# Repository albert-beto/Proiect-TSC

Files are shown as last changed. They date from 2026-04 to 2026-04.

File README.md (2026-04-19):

# InkTime v6

InkTime v6 este o platformă wearable construită pentru autonomie mare și interacțiune discretă. Dispozitivul folosește un display e-paper, conectivitate Bluetooth Low Energy, senzori de mișcare, feedback haptic și alimentare dintr-un acumulator LiPo încărcat prin USB-C.

La nivel de arhitectură, tot sistemul este orchestrat de un **Nordic nRF52840**, care gestionează radio-ul, magistralele digitale și logica de power management.

---

## Ce face dispozitivul

InkTime v6 este gândit ca un smartwatch sau dispozitiv portabil cu consum redus, capabil să rămână activ perioade lungi de timp între încărcări.

Funcțiile principale sunt:

- afișare pe e-paper, cu consum aproape nul în stare statică;
- comunicație BLE;
- detecție de mișcare și numărare pași;
- feedback haptic;
- încărcare prin USB-C;
- monitorizare a stării bateriei.

---

## Diagramă bloc

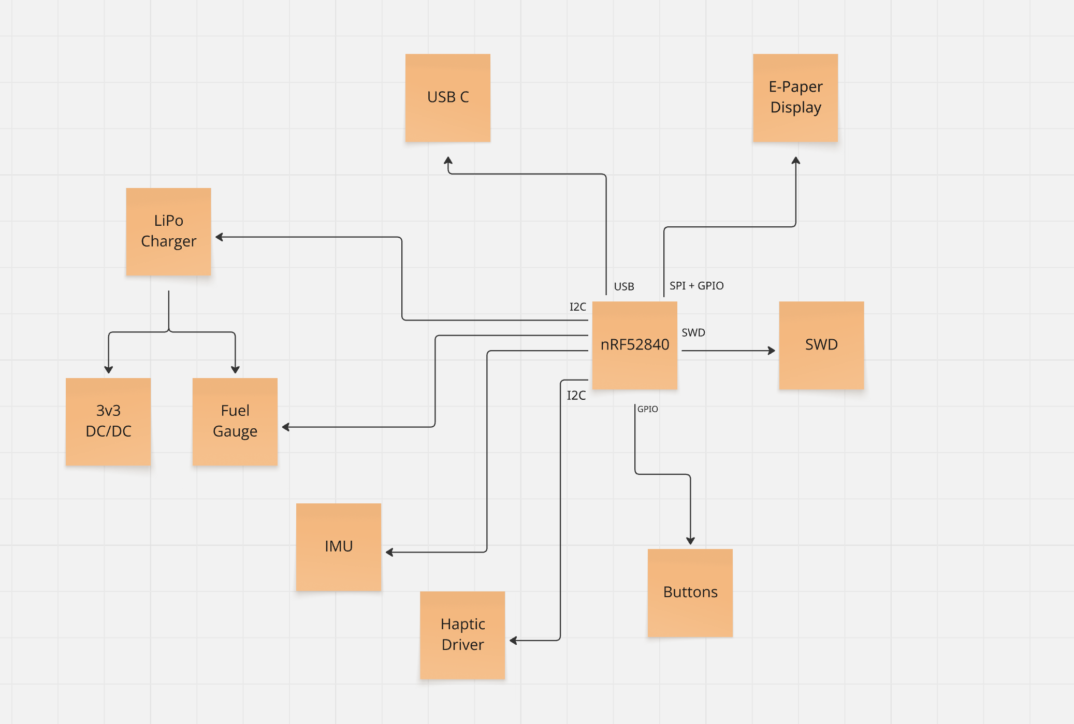
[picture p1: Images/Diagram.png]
Diagrama bloc InkTime


---

## Nucleul sistemului

### nRF52840

Controlerul principal este **nRF52840**, un SoC cu ARM Cortex-M4F, memorie Flash de 1 MB, 256 KB RAM, radio 2.4 GHz multiprotocol și interfață USB 2.0 Full-Speed integrată.

Acesta a fost ales pentru că permite integrarea într-un singur cip a mai multor funcții importante:

- comunicație BLE 5.0;
- control al perifericelor pe I2C și SPI;
- suport USB nativ;
- moduri eficiente de consum redus.

Pentru tactare sunt folosite două cristale externe:

- `X1` — 32 MHz, pentru **HFCLK**;
- `X2` — 32.768 kHz, pentru **LFCLK**.

---

## Interfețe și periferice

### Display e-paper

Interfața principală a utilizatorului este un display e-paper conectat printr-un FPC cu 24 de pini (`J3`). Pentru că afișajul este bistabil, energia este consumată în principal în timpul actualizării, nu în perioada în care imaginea rămâne neschimbată.

Controlul acestui bloc este împărțit în trei părți.

#### 1. Semnale digitale

Comunicarea cu displayul se face printr-o interfață SPI și linii auxiliare:

- `MOSI`
- `SCK`
- `EPD_CS`
- `EPD_DC`
- `EPD_RST`
- `EPD_BUSY`

#### 2. Tensiuni bias pentru panou

Driverul displayului are nevoie de mai multe tensiuni specifice pentru matricea TFT. Acestea sunt obținute cu ajutorul unui mic boost converter și al unei rețele de diode Schottky și condensatoare.

Tensiunile generate sunt:

- `VGH`
- `VGL`
- `VSH`
- `VSL`

#### 3. Oprirea completă a alimentării displayului

Alimentarea de 3.3 V a ansamblului EPD poate fi întreruptă complet printr-un load switch realizat cu MOSFET-ul P-channel **DMG2305UX** (`Q1`). Acesta este comandat de semnalul `EPD_PWR`.

### Accelerometru

Pentru detectarea activității este folosit **BMA423** (`IC2`), un accelerometru digital pe 3 axe.

Rolurile sale în proiect sunt:

- detecția de mișcare;
- step counting;
- generarea de evenimente prin întreruperi.

Componenta este utilizată în **mod I2C**, iar pinul `CSB` este conectat la `VDDIO` pentru a forța această configurație. Cele două ieșiri de întrerupere, `INT1` și `INT2`, sunt rutate separat spre microcontroller.

### Haptic

Blocul de feedback haptic se bazează pe **DRV2605** (`IC1`), controlat pe I2C. Activarea sau dezactivarea lui se face din semnalul `HAPTIC_EN`, conectat la un GPIO al MCU-ului.

Ieșirile `OUT+` și `OUT−` merg direct spre actuatorul haptic.

### Butoane

Sunt implementate trei butoane fizice:

- `SW_UP`
- `SW_DN`
- `SW_ENT`

Fiecare este conectat la câte un GPIO și are:

- pull-up extern de 10 kΩ;
- circuit RC de debounce cu 1 µF la GND.

---

## Alimentare

### USB-C

Conectorul `J1` este un **USB Type-C** (`KH-TYPE-C-16P`) folosit pentru alimentare și pentru conexiunea USB 2.0. În layout sunt rutate doar liniile necesare proiectului.

### Protecție ESD

Pentru protejarea liniilor USB și CC este folosit **USBLC6-2SC6Y**, plasat aproape de conector.

### Încărcător Li-Po

Gestionarea încărcării acumulatorului este făcută de **BQ25180** (`IC4`).

Acest circuit oferă:

- configurare prin I2C;
- curent de încărcare programabil;
- semnalizare de evenimente prin pinul `PMIC_INT`;
- protecție termică.

### Fuel gauge

Monitorizarea bateriei este realizată de **MAX17048** (`U1`), care măsoară tensiunea celulei și estimează nivelul de încărcare.

În design:

- comunică pe magistrala I2C comună;
- folosește semnalul `ALERT` pentru notificări către MCU.

### Convertor DC/DC

Subsistemul de putere include și **RT6160AWSC** (`IC3`), folosit ca convertor DC/DC.

---

## Programare și debug

Pentru flash și depanare este prevăzut un conector **Tag-Connect TC2030-IDC** (`J2`), cu 6 pini, fără header montat permanent pe PCB.

Liniile expuse sunt:

- `VTREF (3.3V)`
- `SWDIO`
- `SWDCLK`
- `SWO`
- `nRESET`
- `GND`

Pe placă există și test pads dedicate:

- `TP_SWDIO`
- `TP_SWDCLK`
- `TP_SWO`
- `TP_RESET`
- `TP_3.3V`
- `TP_GND`

---

## Alocarea pinilor MCU

Mai jos este rezumat mapping-ul relevant pentru nRF52840.

| Pin nRF52840 | Rol | Tip | Observație |
|---|---|---|---|
| **P0.00** | Cristal 32.768 kHz | OSC | Pin dedicat LFXO |
| **P0.01** | Cristal 32.768 kHz | OSC | Pin dedicat LFXO |
| **P0.09** | neconectat | GPIO | rezervat |
| **P0.10** | neconectat | GPIO | rezervat |
| **P0.13** | `MOSI` spre EPD | SPIM | rutare scurtă spre zona displayului |
| **P0.14** | `SCK` spre EPD | SPIM | grupat cu `MOSI` |
| **P0.18** | reset extern | nRESET | pin dedicat |
| **P0.19** | `EPD_CS` | SPIM | asociat interfeței EPD |
| **P0.20** | `EPD_DC` | GPIO | control display |
| **P0.21** | `EPD_RST` | GPIO | reset display |
| **P0.22** | `SWO` | SWO | debug |
| **P0.23** | `EPD_BUSY` | GPIO input + INT | semnal status display |
| **P0.24** | `EPD_PWR` | GPIO | comandă load switch |
| **P0.25** | `HAPTIC_EN` | GPIO | enable pentru DRV2605 |
| **P0.26** | `SDA` | TWIM | magistrală I2C |
| **P0.27** | `SCL` | TWIM | magistrală I2C |
| **P0.28** | neconectat | analog | rezervat |
| **P0.29** | neconectat | GPIO | rezervat |
| **P0.30** | neconectat | GPIO | rezervat |
| **P0.31** | neconectat | GPIO | rezervat |
| **P1.00** | `PMIC_INT` | GPIO input + INT | evenimente de charging |
| **P1.01** | `SW_UP` | GPIO input | buton |
| **P1.02** | `SW_DN` | GPIO input | buton |
| **P1.03** | `SW_ENT` | GPIO input | buton |
| **P1.04** | `IMU_INT1` | GPIO input + INT | eveniment accelerometru |
| **P1.05** | `IMU_INT2` | GPIO input + INT | eveniment accelerometru |
| **P1.06** | `ALERT` | GPIO input + INT | alertă baterie |
| **P1.07** | EPD spre Q3 | GPIO / PWM | comandă auxiliară |
| **SWDCLK** | programare / debug | dedicat | SWD |
| **SWDIO** | programare / debug | dedicat | SWD |
| **VBUS** | detectare USB | USB PHY | sensing VBUS |
| **D+ / D−** | USB 2.0 FS | USB PHY | interfață USB |

---

## Consum și autonomie

### Curent estimat în standby

| Componentă | Curent tipic | Observații |
|---|---:|---|
| nRF52840 (System ON, RAM retention, RTC, LFXO) | ~1.5 µA | radio inactiv |
| BMA423 (low-power, 25 Hz) | ~4 µA | step detection activ |
| BQ25180 (quiescent, no charge) | ~6 µA | |
| MAX17048 (active measurement) | ~23 µA | hibernate ~3 µA |
| DRV2605 (EN=LOW) | < 1 µA | shutdown |
| RT6160 (PFM, fără sarcină) | ~25 µA | ultra-low-quiescent |
| E-paper | ~0 µA | fără refresh |
| Leakage PCB + diode | ~5 µA | estimat |
| **Total** | **≈ 65 µA** | |

### Autonomie estimată pentru 150 mAh

Presupunând un profil de utilizare tipic:

- 23 h 45 min standby la 65 µA → aproximativ 1.54 mAh/zi;
- refresh-uri de ecran → aproximativ 0.2 mAh/zi;
- evenimente haptice → aproximativ 0.01 mAh/zi.

Consum total zilnic estimat:

**≈ 1.75 mAh/zi**

Autonomie rezultată:

**150 mAh / 1.75 mAh pe zi ≈ 85 zile**

---

## Note de implementare

În faza curentă de proiect au fost acceptate câteva compromisuri și excepții:

- pentru rezistoare și condensatoare mici au fost păstrate modele 3D placeholder;
- au fost aprobate 6 erori legate de modelele 3D ale butoanelor;
- au fost acceptate erori de tip **Overlap** și **Copper clearance** asociate utilizării tehnicii **via-in-pad**.

---

## Concluzie tehnică

InkTime v6 este un sistem compact orientat spre consum redus, în care displayul bistabil, BLE-ul, senzorii și managementul de putere sunt integrate în jurul nRF52840. Arhitectura a fost gândită pentru un dispozitiv portabil capabil să ofere autonomie mare, funcții utile de interacțiune și o interfață modernă cu utilizatorul.

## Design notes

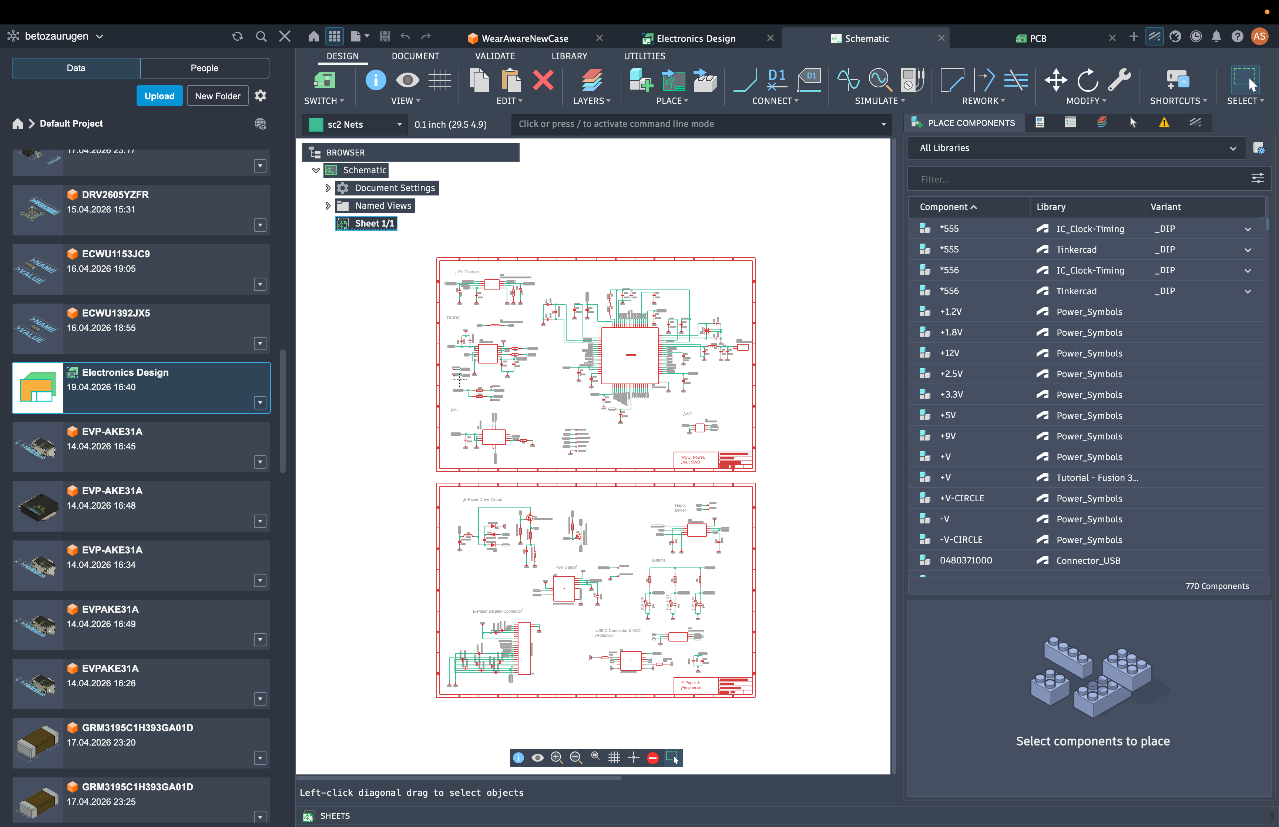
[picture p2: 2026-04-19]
Images/IntTime3.png

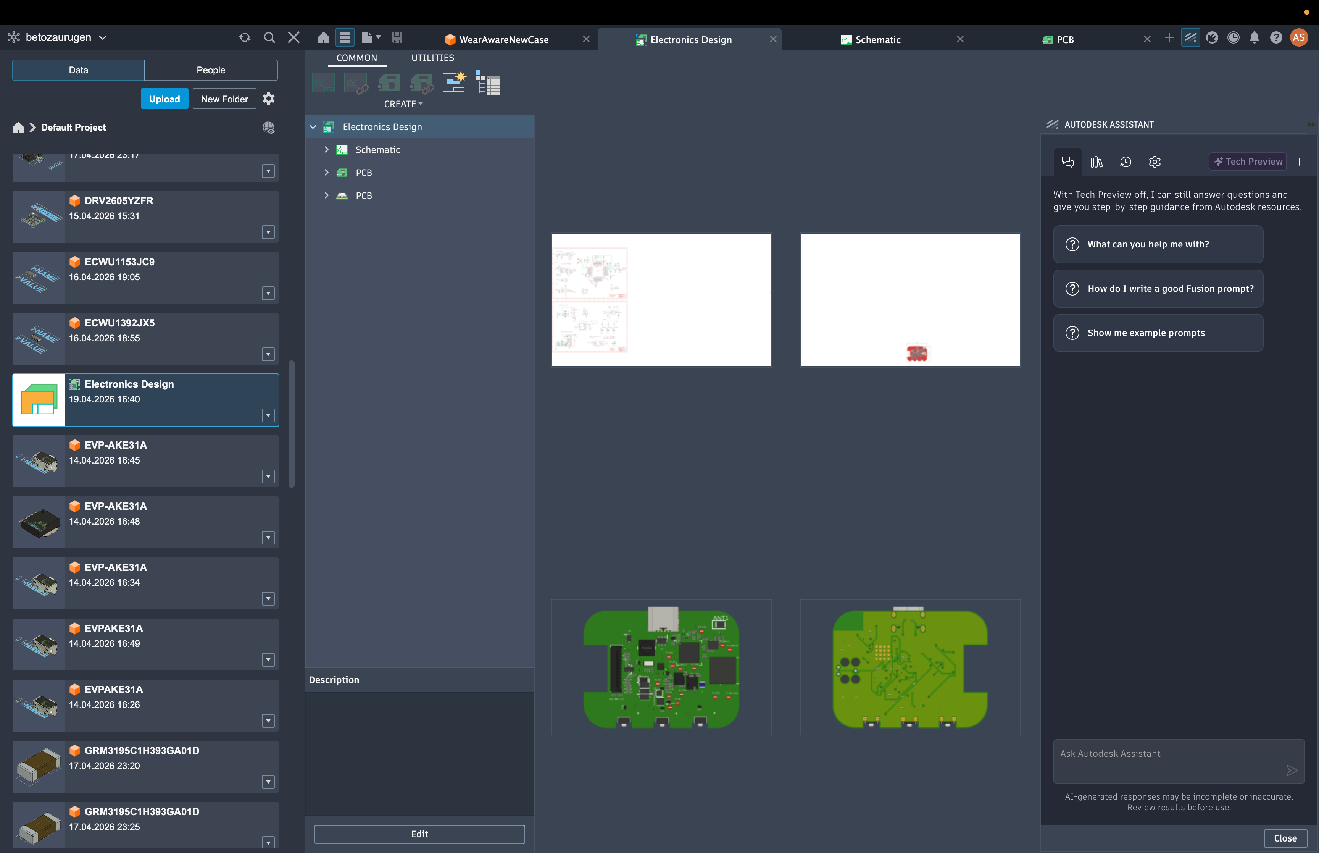
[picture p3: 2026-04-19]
Images/InkTime4.png

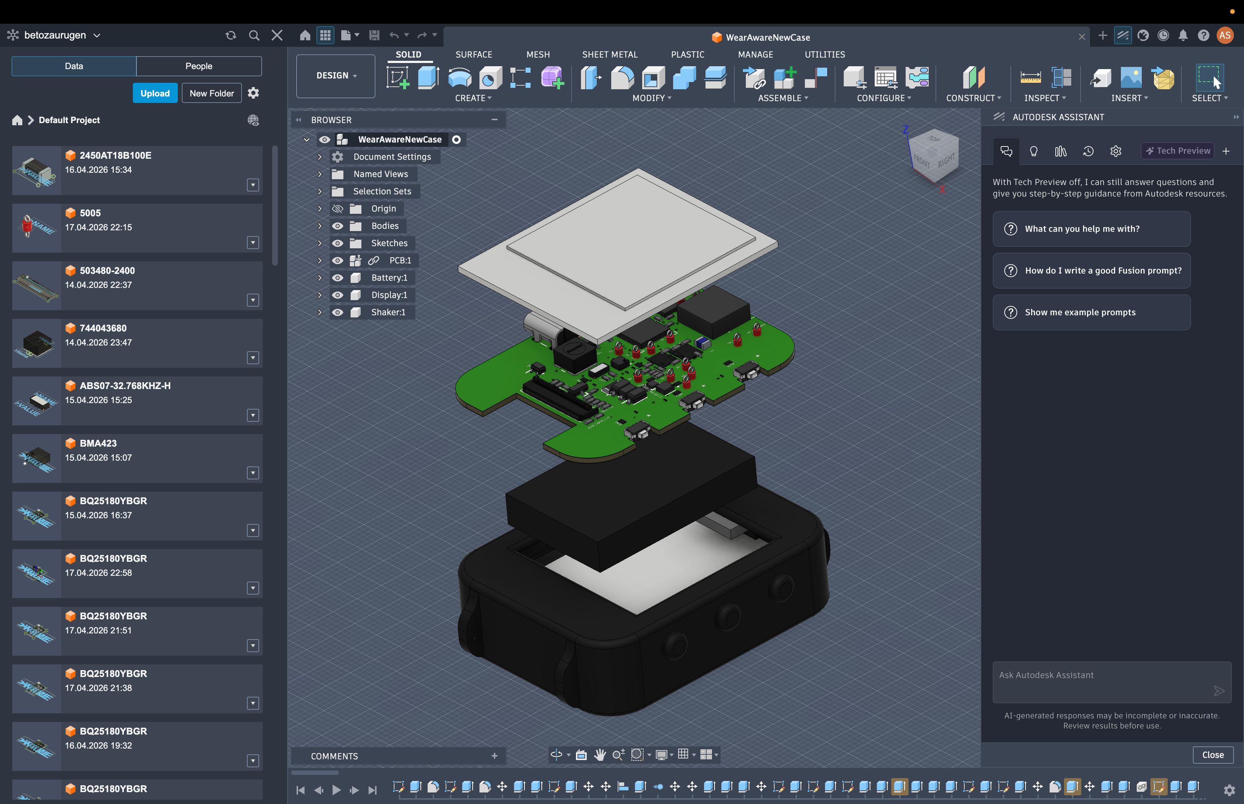
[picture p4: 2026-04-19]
Images/InkTime1.png

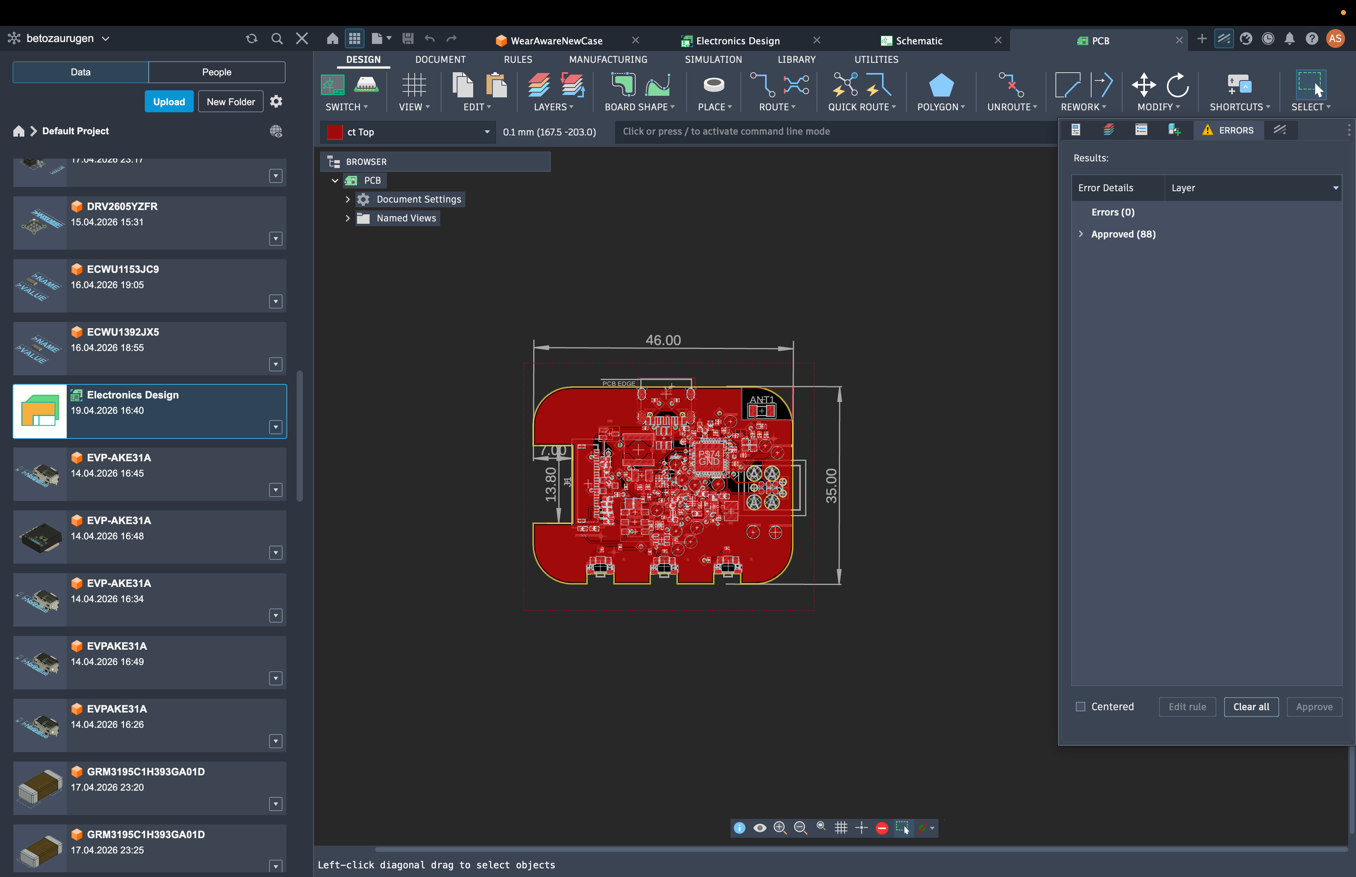
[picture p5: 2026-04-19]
Images/InkTime2.png

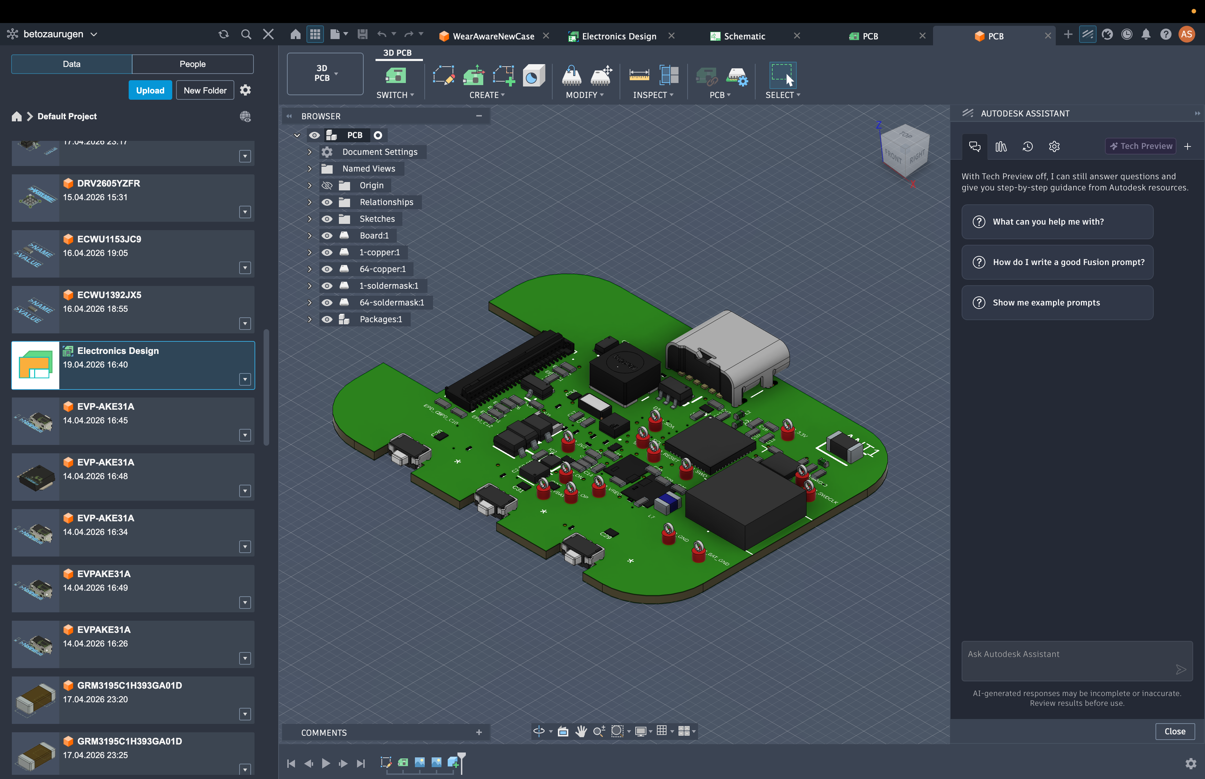
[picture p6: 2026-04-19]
Images/InkTime5.png

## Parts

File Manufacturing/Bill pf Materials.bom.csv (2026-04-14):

Qty | Value | Device | Package | Parts | Description | ARROW_PART_NUMBER | ARROW_PRICE-STOCK | AVAILABILITY | CHECK_PRICES | COPYRIGHT | DESCRIPTION | DIGI-KEY_PART_NUMBER_1 | DIGI-KEY_PART_NUMBER_2 | DIGI-KEY_PART_NUMBER_3 | HEIGHT | JLCPCB | MANUFACTURER_NAME | MANUFACTURER_PART_NUMBER | MF | MFR_NAME | MOUSER_PART_NUMBER | MOUSER_PRICE-STOCK | MP | PACKAGE | POPULARITY | PRICE | PROD_ID | PURCHASE-URL | SNAPEDA_LINK | TP_SIGNAL_NAME | VALUE
3 |  | 2025-10-22_07-23-44_LIBRARY_EVP-AKE31ASW_EVP-AKE31A_PAN | 2025-10-22_07-23-44_LIBRARY_SW_EVP-AKE31A_PAN | SW_DN, SW_ENT, SW_UP |  |  |  |  |  | Copyright (C) 2025 Ultra Librarian. All rights reserved. |  | P123437TR-ND | P123437CT-ND | P123437DKR-ND |  |  | Panasonic | EVP-AKE31A
1 |  | ESP32_C6_LIBRARY_7_JUMPER_SJ | ESP32_C6_LIBRARY_7_JUMPER_SJ | SJ1 | SMD solder JUMPER |  |  |  |  |  |  |  |  |  |  |  |  |  |  |  |  |  |  |  | 3
3 | 0 | CPF0201D7K68C1_CPF0201D7K68C1 | CPF0201D7K68C1_0201 | R2, R3, R4 | 7.68k 0201 Thin Film Surface Mount Fixed Resistor +/-0.5% 0.031W CPF0201D7K68C1
4 | 0.1uF | GRM011R60J152KE01L_2_GRM011R60J152KE01L | GRM011R60J152KE01L_2_CAPC0201X13N | C23, C27, C34, C42 | Check availability |  |  | In Stock | https://www.snapeda.com/parts/GRM011R60J152KE01L/Murata/view-part/?ref=eda |  | SMD Capacitor X5R(EIA) with Capacitance: 1500pF Tol. 10%. Rated Voltage: 6.3Vdc |  |  |  |  |  |  |  | Murata |  |  |  | GRM011R60J152KE01L | 0201 Murata |  | None |  |  | https://www.snapeda.com/parts/GRM011R60J152KE01L/Murata/view-part/?ref=snap
1 | 0.1uF/50V | NORDIC_NRF_3_CAPACITOR_0201_L | NORDIC_NRF_3_RESC0201_L | EPD-C5 | Generic chip capacitor
1 | 0.47 | CPF0201D7K68C1_CPF0201D7K68C1 | CPF0201D7K68C1_0201 | R1_EP_DR | 7.68k 0201 Thin Film Surface Mount Fixed Resistor +/-0.5% 0.031W CPF0201D7K68C1
1 | 1.0uF | NORDIC_NRF_3_CAPACITOR_0402_L | NORDIC_NRF_3_RESC0402_L | C15 | Generic chip capacitor
4 | 100nF | NORDIC_NRF_3_CAPACITOR_0201_L | NORDIC_NRF_3_RESC0201_L | C5, C7, C8, C12 | Generic chip capacitor
1 | 100pF | NORDIC_NRF_3_CAPACITOR_0201_L | NORDIC_NRF_3_RESC0201_L | C11 | Generic chip capacitor
5 | 10K | CPF0201D7K68C1_CPF0201D7K68C1 | CPF0201D7K68C1_0201 | R2_EP_DR, R5, R7, R8, R_POWER_EPD | 7.68k 0201 Thin Film Surface Mount Fixed Resistor +/-0.5% 0.031W CPF0201D7K68C1
1 | 10K | ERA-1AEB3401C_CPF0201D7K68C1 | ERA-1AEB3401C_0201 | R1 | 7.68k 0201 Thin Film Surface Mount Fixed Resistor +/-0.5% 0.031W CPF0201D7K68C1
3 | 10uF | NORDIC_NRF_3_CAPACITOR_0402_L | NORDIC_NRF_3_RESC0402_L | C1-EP-DR, C24, C39 | Generic chip capacitor
1 | 10µH | NORDIC_NRF_2_INDUCTOR_0402_L | NORDIC_NRF_2_RESC0402_L | L2 | Generic chip inductor
4 | 12pF | NORDIC_NRF_3_CAPACITOR_0201_L | NORDIC_NRF_3_RESC0201_L | C1, C2, C17, C18 | Generic chip capacitor
1 | 15nH | NORDIC_NRF_2_INDUCTOR_0402_L | NORDIC_NRF_2_RESC0402_L | L3 | Generic chip inductor
2 | 1pF | NORDIC_NRF_3_CAPACITOR_0201_L | NORDIC_NRF_3_RESC0201_L | C3, C4 | Generic chip capacitor
6 | 1uF | GRM011R60J152KE01L_2_GRM011R60J152KE01L | GRM011R60J152KE01L_2_CAPC0201X13N | C29, C30, C31, C32, C37, C38 | Check availability |  |  | In Stock | https://www.snapeda.com/parts/GRM011R60J152KE01L/Murata/view-part/?ref=eda |  | SMD Capacitor X5R(EIA) with Capacitance: 1500pF Tol. 10%. Rated Voltage: 6.3Vdc |  |  |  |  |  |  |  | Murata |  |  |  | GRM011R60J152KE01L | 0201 Murata |  | None |  |  | https://www.snapeda.com/parts/GRM011R60J152KE01L/Murata/view-part/?ref=snap
9 | 1uF/50V | NORDIC_NRF_3_CAPACITOR_0402_L | NORDIC_NRF_3_RESC0402_L | EPD_C1, EPD_C2, EPD_C6, EPD_C7, EPD_C8, EPD_C9, EPD_C10, EPD_C11, EPD_C12 | Generic chip capacitor
1 | 2.2 | CPF0201D7K68C1_CPF0201D7K68C1 | CPF0201D7K68C1_0201 | R_TYPE_SEL | 7.68k 0201 Thin Film Surface Mount Fixed Resistor +/-0.5% 0.031W CPF0201D7K68C1
1 | 20V/4.2A/52mΩ/1.4W | ESP32_C6_LIBRARY_4_ESP32_WROVER_SPARKFUN-DISCRETESEMI_MOSFET_PCH-DMG2305UX-7 | ESP32_C6_LIBRARY_4_ESP32_C6_LIBRARY_4_ESP32_C6_LIBRARY_4_ESP32_C6_LIBRARY_4_ESP32_WROVER_SPARKFUN-DISCRETESEMI_SOT23-3 | Q1 | P-channel MOSFETs |  |  |  |  |  |  |  |  |  |  |  |  |  |  |  |  |  |  |  |  |  | TRAN-14388 |  |  |  | 20V/4.2A/52mΩ/1.4W
2 | 22uF | NORDIC_NRF_3_CAPACITOR_0201_L | NORDIC_NRF_3_RESC0201_L | C19, C33 | Generic chip capacitor
1 | 22uF | NORDIC_NRF_3_CAPACITOR_0402_L | NORDIC_NRF_3_RESC0402_L | C25 | Generic chip capacitor
1 | 2450AT18B100E | 2450AT18B100E_2450AT18B100E | 2450AT18B100E_ANTC3216X140N | ANT1 | Antennas 2.45GHz ANTENNA | 2450AT18B100E | https://www.arrow.com/en/products/2450at18b100e/johanson-dielectrics?utm_currency=USD&region=nac |  |  |  | Antennas 2.45GHz ANTENNA |  |  |  | 1.4mm |  | JOHANSON TECHNOLOGY | 2450AT18B100E |  |  | 609-2450AT18B100E | https://www.mouser.co.uk/ProductDetail/Johanson-Technology/2450AT18B100E?qs=yCnrNFeXz%252Bh5MFsFIXGZGA%3D%3D
1 | 3.9nH | NORDIC_NRF_2_INDUCTOR_0402_L | NORDIC_NRF_2_RESC0402_L | L1 | Generic chip inductor
1 | 32.768kHz | NORDIC_NRF_1_XTAL_32KHZ | NORDIC_NRF_1_XTAL_3215_N | X2
1 | 32MHz | NORDIC_NRF_XTAL_32MHZ | NORDIC_NRF_BT-XTAL_2016_N | X1
2 | 3K3 | CPF0201D7K68C1_CPF0201D7K68C1 | CPF0201D7K68C1_0201 | R17, R18 | 7.68k 0201 Thin Film Surface Mount Fixed Resistor +/-0.5% 0.031W CPF0201D7K68C1
2 | 4.7uF | NORDIC_NRF_3_CAPACITOR_0402_L | NORDIC_NRF_3_RESC0402_L | C14, C43 | Generic chip capacitor
1 | 4.7uF/25V | NORDIC_NRF_3_CAPACITOR_0402_L | NORDIC_NRF_3_RESC0402_L | C2-EP-DR | Generic chip capacitor
3 | 4.7µF | NORDIC_NRF_3_CAPACITOR_0402_L | NORDIC_NRF_3_RESC0402_L | C6, C20, C21 | Generic chip capacitor
1 | 47nF | NORDIC_NRF_3_CAPACITOR_0201_L | NORDIC_NRF_3_RESC0201_L | C16 | Generic chip capacitor
1 | 503480-2400 | 503480-2400_503480-2400 | 503480-2400_5034802400 | J1 | FFC & FPC Connectors 0.5mm FPC RA SMT Dual Contact 24Ckt |  |  |  |  |  | FFC & FPC Connectors 0.5mm FPC RA SMT Dual Contact 24Ckt |  |  |  | 1.87mm |  | Molex | 503480-2400 |  |  | 538-503480-2400 | https://www.mouser.co.uk/ProductDetail/Molex/503480-2400?qs=OAhjpuo3Vu7efIoxFh9AOw%3D%3D
2 | 5K1 | CPF0201D7K68C1_CPF0201D7K68C1 | CPF0201D7K68C1_0201 | R1_USB, R2_USB | 7.68k 0201 Thin Film Surface Mount Fixed Resistor +/-0.5% 0.031W CPF0201D7K68C1
1 | 68uH | ESP32_C6_LIBRARY_2_744043680IND_4828-WE-TPC_WRE | ESP32_C6_LIBRARY_2_IND_4828-WE-TPC_WRE | L5 |  |  |  |  |  | Copyright (C) 2024 Ultra Librarian. All rights reserved. |  |  |  |  |  |  |  | 744043680 |  | Wurth Electronics
1 | 820pF | NORDIC_NRF_3_CAPACITOR_0201_L | NORDIC_NRF_3_RESC0201_L | C9 | Generic chip capacitor
1 | BMA421 | BMA423_BMA423 | BMA423_BMA423 | IC3 | Accelerometers Triaxial low-g 12bit Acceleration Sensor | BMA423 | https://www.arrow.com/en/products/bma423/bosch |  |  |  | Accelerometers Triaxial low-g 12bit Acceleration Sensor |  |  |  | 1mm |  | BOSCH | BMA423 |  |  | 262-BMA423 | https://www.mouser.co.uk/ProductDetail/Bosch-Sensortec/BMA423?qs=HXFqYaX1Q2xC%252BSgeGoX3mg%3D%3D
1 | BQ25180YBGR_BQ25180YBGR | BQ25180YBGR_BQ25180YBGR | BQ25180YBGR_BGA8C40P2X4_100X155X50 | IC1 | Charger IC Lithium Ion/Polymer, Lithium Iron Phosphate 8-DSBGA (1.6x1.1) | BQ25180YBGR | https://www.arrow.com/en/products/bq25180ybgr/texas-instruments?utm_currency=USD&region=nac |  |  |  | Charger IC Lithium Ion/Polymer | Lithium Iron Phosphate 8-DSBGA (1.6x1.1) |  |  |  | 0.5mm |  | Texas Instruments | BQ25180YBGR |  |  | 595-BQ25180YBGR | https://www.mouser.co.uk/ProductDetail/Texas-Instruments/BQ25180YBGR?qs=doiCPypUmgEWjAK%252BJAX6Tw%3D%3D
1 | DRV2605YZFR | DRV2605YZFR_DRV2605YZFR | DRV2605YZFR_BGA9C50P3X3_144X144X62 | IC2 | Haptic Driver for ERM/LRA with Built-In Library and Smart Loop Architecture | DRV2605YZFR | https://www.arrow.com/en/products/drv2605yzfr/texas-instruments?region=nac |  |  |  | Haptic Driver for ERM/LRA with Built-In Library and Smart Loop Architecture |  |  |  | 0.625mm |  | Texas Instruments | DRV2605YZFR
1 | FTC252012SR47MBCA | MLP2016SR47MT0S1_FTC252012SR47MBCA | MLP2016SR47MT0S1_INDC2016X100N | L7 | SMD / SMT Inductors (Coils), L=0.47?H, L x W x T : |  |  |  |  |  | SMD / SMT Inductors (Coils) | L=0.47?H | L x W x T : |  |  |  | 1mm | https://jlcpcb.com/partdetail/6763488-FTC252012SR47MBCA/C5832368 | TDK | FTC252012SR47MBCA
14 | HECTOR_WATCH_1_TPTP20R | HECTOR_WATCH_1_TPTP20R | HECTOR_WATCH_1_TP20R | TP_3.3V, TP_3V3, TP_BAT_GND, TP_GND, TP_ON, TP_OP, TP_RESET, TP_SCL, TP_SDA, TP_SWDCLK, TP_SWDIO, TP_SWO, TP_VBAT, TP_VREG | Test pad |  |  |  |  |  |  |  |  |  |  |  |  |  |  |  |  |  |  |  | 2
1 | KH-TYPE-C-16P | KH-TYPE-C-16P_KH-TYPE-C-16P | KH-TYPE-C-16P_KINGHELM_KH-TYPE-C-16P | J4 | Check availability |  |  | Not in stock | https://www.snapeda.com/parts/KH-TYPE-C-16P/Kinghelm/view-part/?ref=eda |  |  |  |  |  |  |  |  |  | kinghelm |  |  |  | KH-TYPE-C-16P | None |  | None |  |  | https://www.snapeda.com/parts/KH-TYPE-C-16P/Kinghelm/view-part/?ref=snap
1 | MAX17048G+T10 | ESP32_C6_LIBRARY_MAX17048G+T10 | ESP32_C6_LIBRARY_SON50P200X200X80-9N | U3 | Check availability |  |  | In Stock | https://www.snapeda.com/parts/MAX17048G+T10/Analog+Devices/view-part/?ref=eda |  | 3µA 1-Cell/2-Cell Fuel Gauge with ModelGauge |  |  |  |  |  |  |  | Analog Devices |  |  |  | MAX17048G+T10 | TDFN-8 Maxim |  | None |  | https://www.snapeda.com/api/url_track_click_mouser/?unipart_id=329239&manufacturer=Analog Devices&part_name=MAX17048G+T10&search_term=None | https://www.snapeda.com/parts/MAX17048G+T10/Analog+Devices/view-part/?ref=snap
3 | MBR0530 | ESP32_C6_LIBRARY_5_MBR0530 | ESP32_C6_LIBRARY_5_SOD3716X135N | D2, D4, D5 | ON SEMICONDUCTOR - MBR0530 - DIODE, SCHOTTKY, 0.5A, 30V, SOD-123 |  |  | In Stock | https://www.snapeda.com/parts/MBR0530/Onsemi/view-part/?ref=eda |  | Diode Schottky 30 V 500mA Surface Mount SOD-123 |  |  |  |  |  |  |  | ON Semiconductor |  |  |  | MBR0530 | SOD-123-2 ON Semiconductor |  | None |  | https://www.snapeda.com/api/url_track_click_mouser/?unipart_id=179458&manufacturer=ON Semiconductor&part_name=MBR0530&search_term=None | https://www.snapeda.com/parts/MBR0530/Onsemi/view-part/?ref=snap
3 | N.C. | NORDIC_NRF_3_CAPACITOR_0201_L | NORDIC_NRF_3_RESC0201_L | C10, C13, C22 | Generic chip capacitor
1 | NRF52840_QF | NORDIC_NRF_4_NRF52840_QF | NORDIC_NRF_4_AQFN50P700X700X85_HS-74N | U1 | nRF52840
1 | RT6160AWSC | RT6160AWSC_RT6160AWSC | RT6160AWSC_BGA15C40P3X5_140X230X60 | IC9 | Buck-Boost Regulator Positive Output Step-Up/Step-Down I2C DC-DC Controller IC 15-WL-CSP (BSC) (1.4x2.3) |  |  |  |  |  | Buck-Boost Regulator Positive Output Step-Up/Step-Down I2C DC-DC Controller IC 15-WL-CSP (BSC) (1.4x2.3) |  |  |  | 0.6mm |  | RICHTEK | RT6160AWSC |  |  | 835-RT6160AWSC | https://www.mouser.co.uk/ProductDetail/Richtek/RT6160AWSC?qs=amGC7iS6iy%2FLd9PSoixZXQ%3D%3D
1 | SI1308EDL-T1-GE3 | ESP32_C6_LIBRARY_6_SI1308EDL-T1-GE3 | ESP32_C6_LIBRARY_6_SOT65P210X110-3N | Q3 | MOSFET N-Ch 30V 1.5A TrenchFET SC70 Vishay Si1308EDL-T1-GE3 N-channel MOSFET Transistor, 1.5 A, 30 V, 3-Pin SC-70 |  |  | In Stock | https://www.snapeda.com/parts/SI1308EDL-T1-GE3/Vishay+Siliconix/view-part/?ref=eda |  | Si1308EDL-T1-GE3 N-channel MOSFET Transistor | 1.5 A | 30 V | 3-Pin SC-70 | Siliconix / Vishay SI1308EDL-T1-GE3 |  |  |  |  |  |  |  | Vishay Siliconix |  |  |  | SI1308EDL-T1-GE3 | SOT-323 Vishay Semiconductor |  | None |  | https://www.snapeda.com/api/url_track_click_mouser/?unipart_id=274603&manufacturer=Vishay Siliconix&part_name=SI1308EDL-T1-GE3&search_term=None
1 | TC2030-IDC | TC2030-IDC_TC2030-IDC | TC2030-IDC_TC2030IDC | J2 | CABLE ADAPTER 6 POS |  |  |  |  |  | CABLE ADAPTER 6 POS |  |  |  | 19mm |  | Tag Connect | TC2030-IDC
1 | USBLC6-2SC6Y | ESP32_C6_LIBRARY_3_USBLC6-2SC6Y | ESP32_C6_LIBRARY_3_SOT95P280X145-6N | D3 | Low Cap. ESD Protection Auto SOT-23-6 STMicroelectronics USBLC6-2SC6Y, Dual Uni-Directional TVS Diode Array, 6-Pin SOT-23 |  |  | In Stock | https://www.snapeda.com/parts/USBLC6-2SC6Y/STMicroelectronics/view-part/?ref=eda |  | 17V Clamp 5A (8/20µs) Ipp Tvs Diode Surface Mount SOT-23-6 |  |  |  |  |  |  |  | STMicroelectronics |  |  |  | USBLC6-2SC6Y | SOT-23-6 STMicroelectronics |  | None |  |  | https://www.snapeda.com/parts/USBLC6-2SC6Y/STMicroelectronics/view-part/?ref=snap

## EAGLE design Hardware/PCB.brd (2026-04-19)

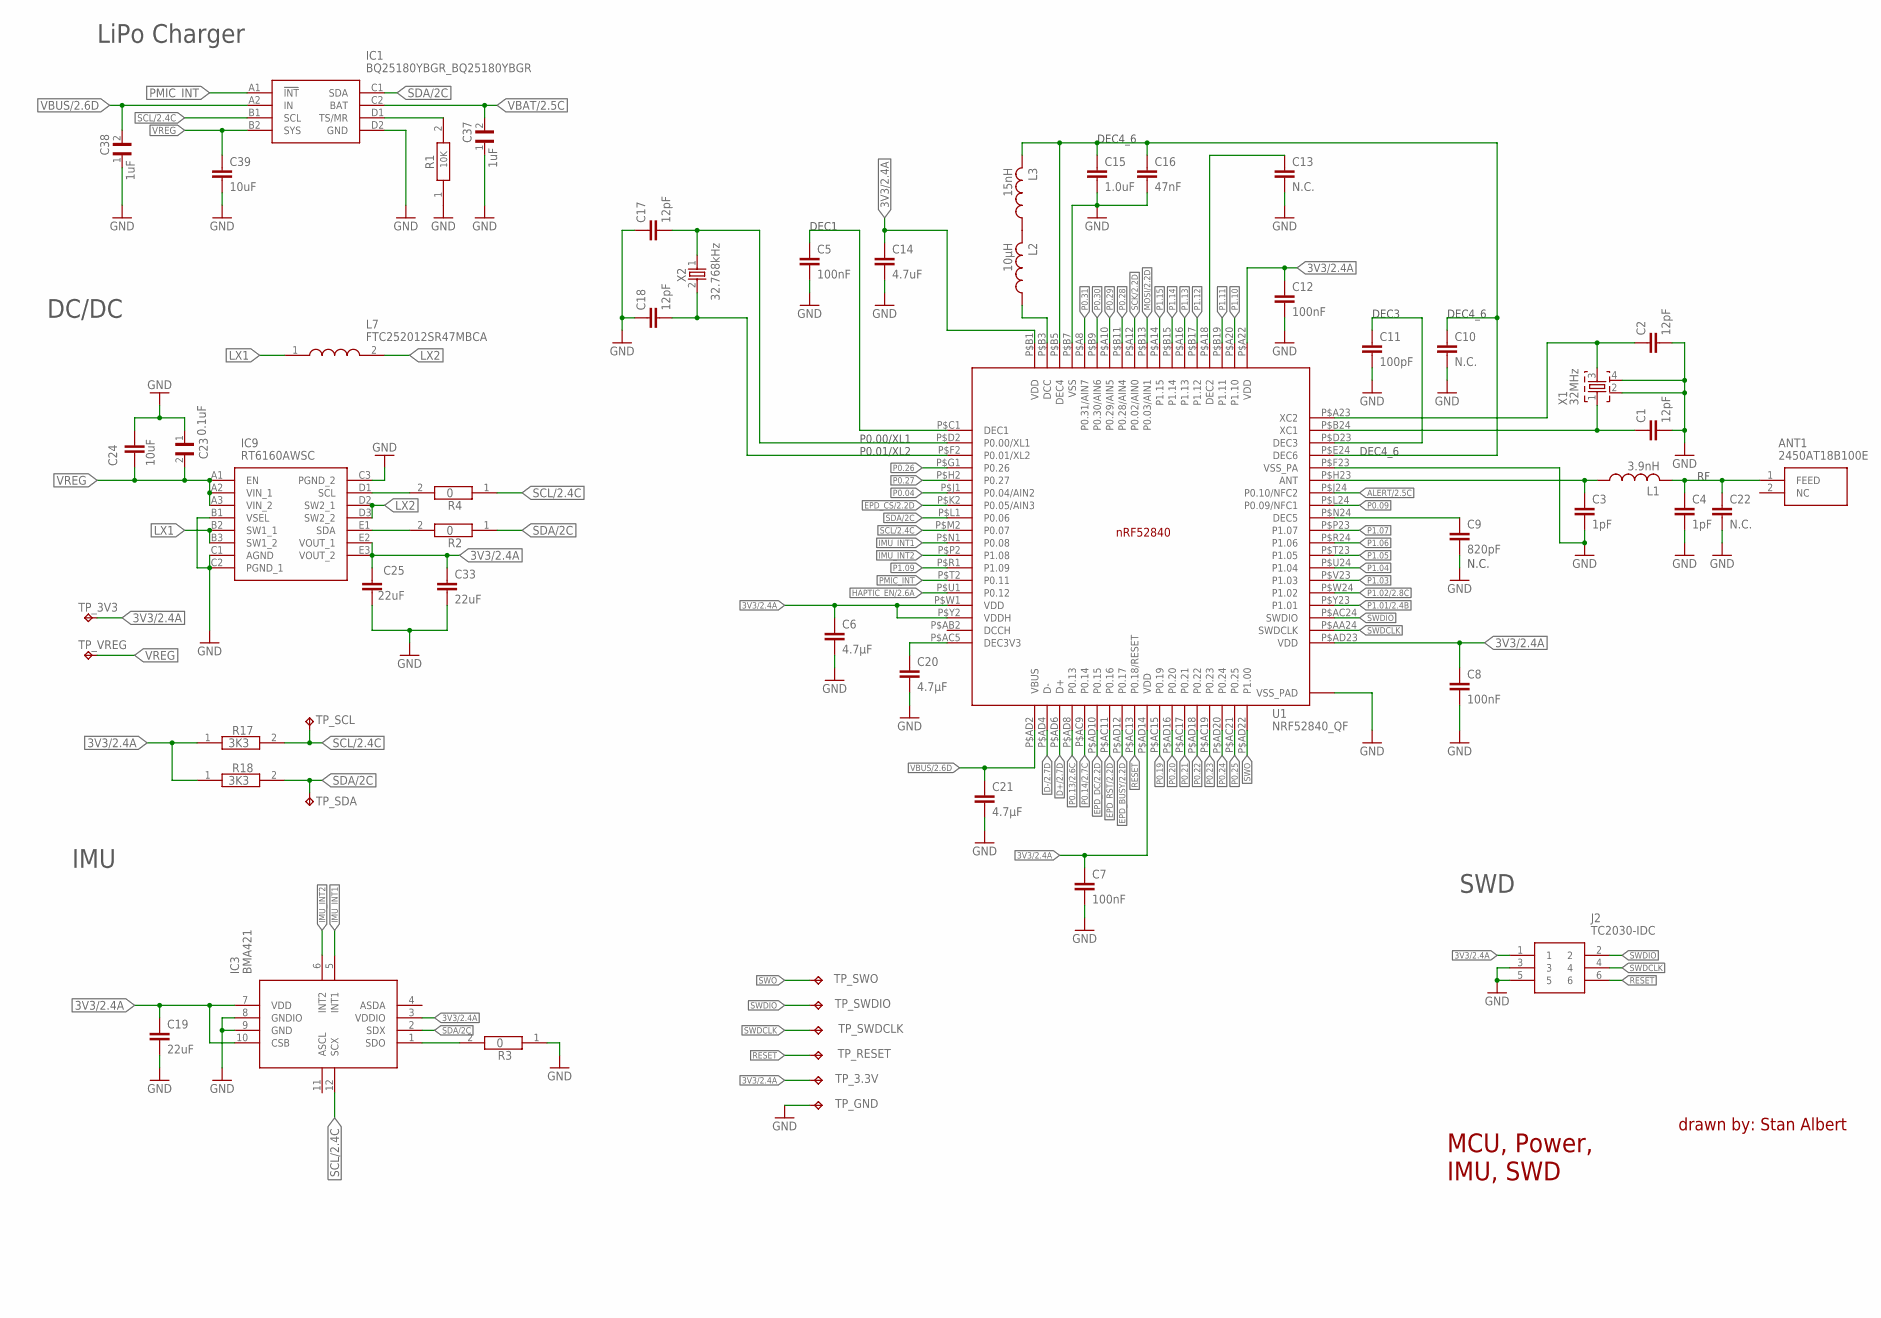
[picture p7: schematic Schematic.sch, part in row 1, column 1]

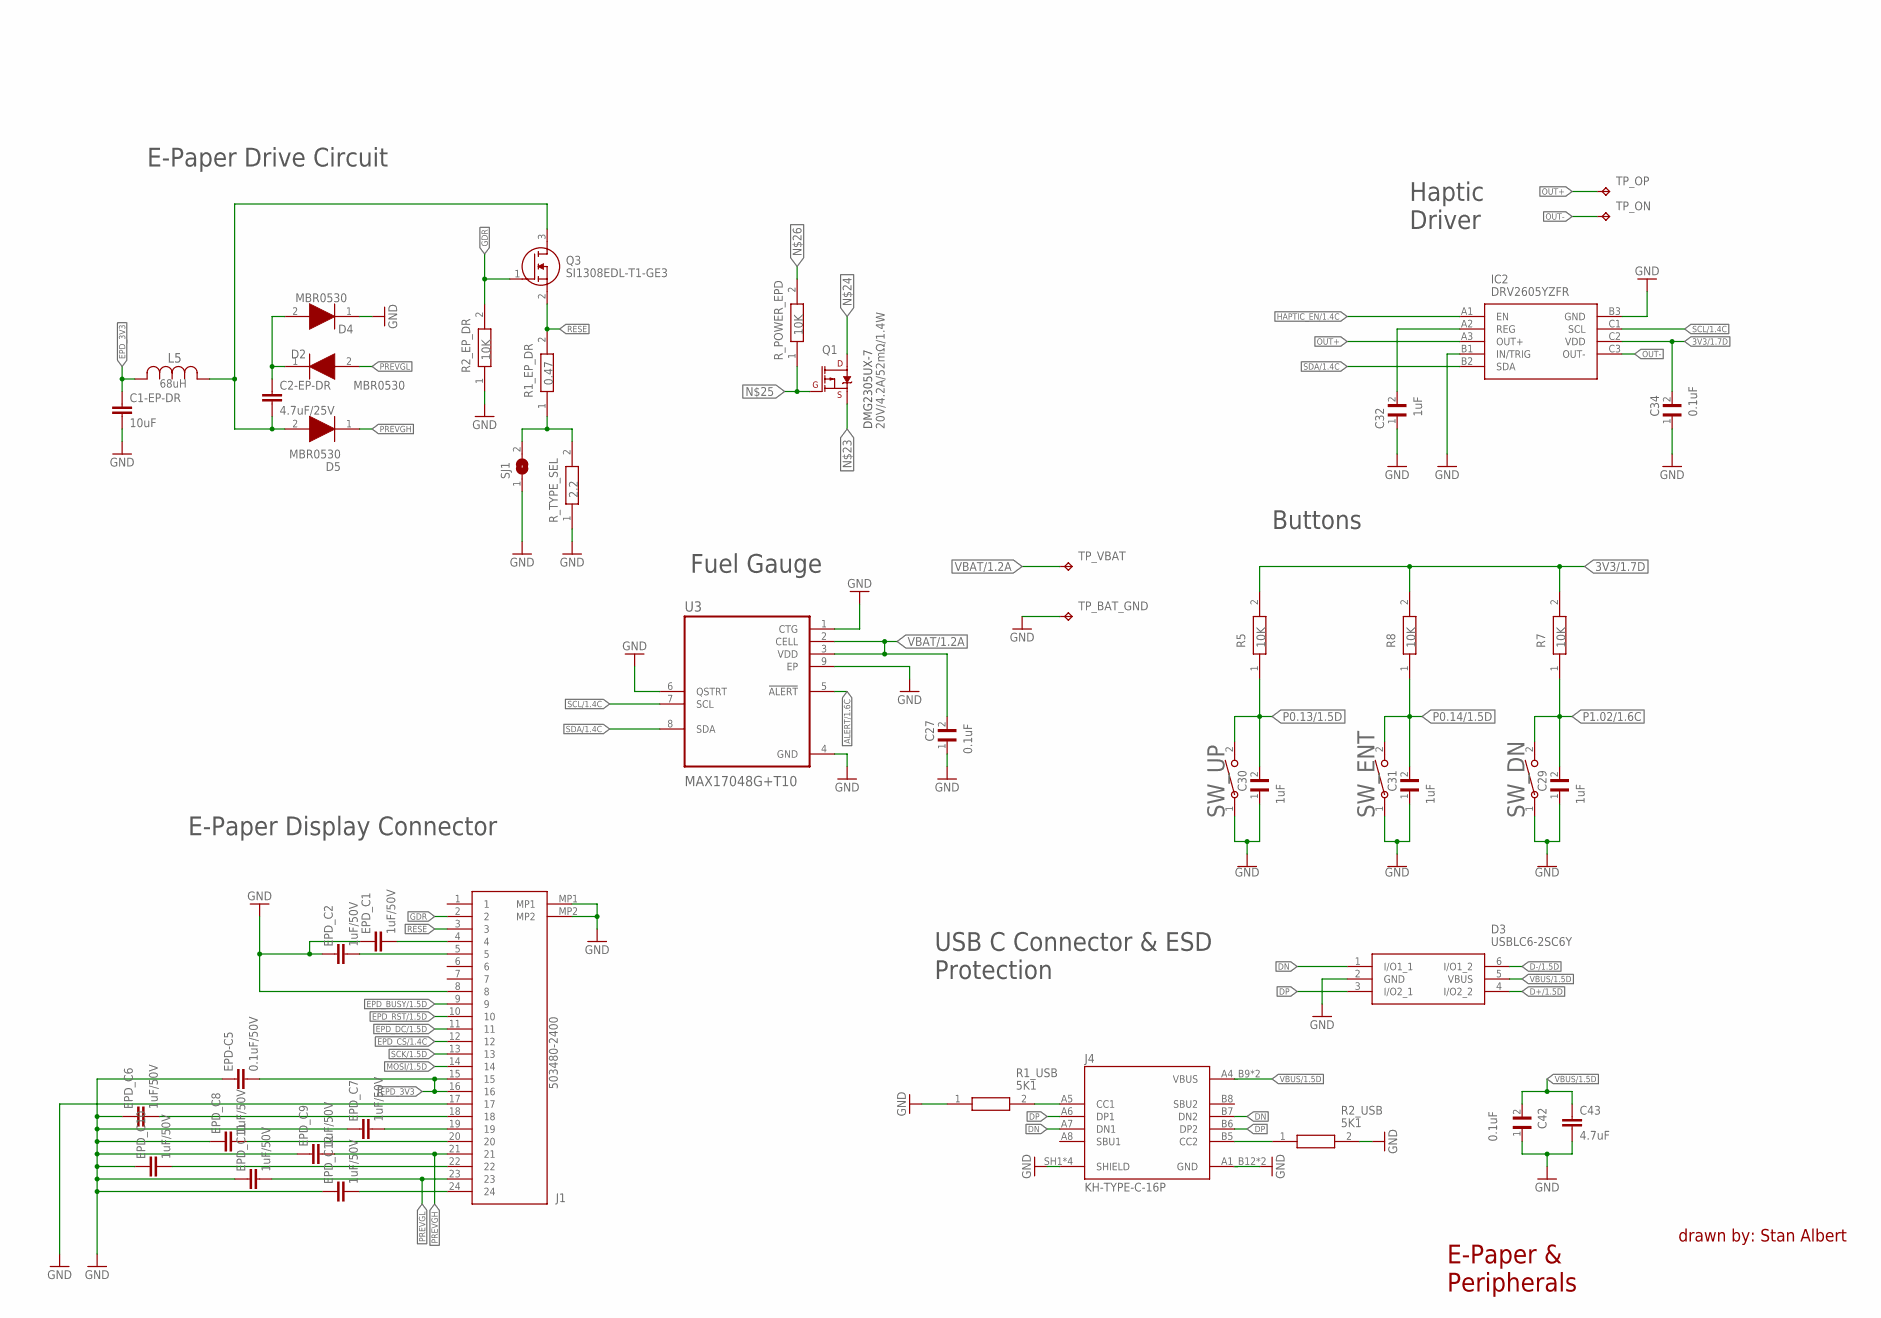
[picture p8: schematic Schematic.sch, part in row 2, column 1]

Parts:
ANT1: 2450AT18B100E; 2450AT18B100E_ANTC3216X140N
C1, C2, C17, C18: 12pF; NORDIC_NRF_3_RESC0201_L
C1-EP-DR, C24, C39: 10uF; NORDIC_NRF_3_RESC0402_L
C2-EP-DR: 4.7uF/25V; NORDIC_NRF_3_RESC0402_L
C3, C4: 1pF; NORDIC_NRF_3_RESC0201_L
C5, C7, C8, C12: 100nF; NORDIC_NRF_3_RESC0201_L
C6, C20, C21: 4.7µF; NORDIC_NRF_3_RESC0402_L
C9: 820pF; NORDIC_NRF_3_RESC0201_L
C10, C13, C22: N.C.; NORDIC_NRF_3_RESC0201_L
C11: 100pF; NORDIC_NRF_3_RESC0201_L
C14, C43: 4.7uF; NORDIC_NRF_3_RESC0402_L
C15: 1.0uF; NORDIC_NRF_3_RESC0402_L
C16: 47nF; NORDIC_NRF_3_RESC0201_L
C19, C33: 22uF; NORDIC_NRF_3_RESC0201_L
C23, C27, C34, C42: 0.1uF; GRM011R60J152KE01L_2_CAPC0201X13N
C25: 22uF; NORDIC_NRF_3_RESC0402_L
C29, C30, C31, C32, C37, C38: 1uF; GRM011R60J152KE01L_2_CAPC0201X13N
D2, D4, D5: MBR0530; ESP32_C6_LIBRARY_5_SOD3716X135N
D3: USBLC6-2SC6Y; ESP32_C6_LIBRARY_3_SOT95P280X145-6N
EPD-C5: 0.1uF/50V; NORDIC_NRF_3_RESC0201_L
EPD_C1, EPD_C2, EPD_C6, EPD_C7, EPD_C8, EPD_C9, EPD_C10, EPD_C11, EPD_C12: 1uF/50V; NORDIC_NRF_3_RESC0402_L
IC1: BQ25180YBGR_BQ25180YBGR; BQ25180YBGR_BGA8C40P2X4_100X155X50
IC2: DRV2605YZFR; DRV2605YZFR_BGA9C50P3X3_144X144X62
IC3: BMA421; BMA423_BMA423
IC9: RT6160AWSC; RT6160AWSC_BGA15C40P3X5_140X230X60
J1: 503480-2400; 503480-2400_5034802400
J2: TC2030-IDC; TC2030-IDC_TC2030IDC
J4: KH-TYPE-C-16P; KH-TYPE-C-16P_KINGHELM_KH-TYPE-C-16P
L1: 3.9nH; NORDIC_NRF_2_RESC0402_L
L2: 10µH; NORDIC_NRF_2_RESC0402_L
L3: 15nH; NORDIC_NRF_2_RESC0402_L
L5: 68uH; ESP32_C6_LIBRARY_2_IND_4828-WE-TPC_WRE
L7: FTC252012SR47MBCA; MLP2016SR47MT0S1_INDC2016X100N
Q1: 20V/4.2A/52mΩ/1.4W; ESP32_C6_LIBRARY_4_ESP32_C6_LIBRARY_4_ESP32_C6_LIBRARY_4_ES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
Q3: SI1308EDL-T1-GE3; ESP32_C6_LIBRARY_6_SOT65P210X110-3N
R1: 10K; ERA-1AEB3401C_0201
R1_EP_DR: 0.47; CPF0201D7K68C1_0201
R1_USB, R2_USB: 5K1; CPF0201D7K68C1_0201
R2, R3, R4: 0; CPF0201D7K68C1_0201
R2_EP_DR, R5, R7, R8: 10K; CPF0201D7K68C1_0201
R17, R18: 3K3; CPF0201D7K68C1_0201
R_POWER_EPD: 10K; CPF0201D7K68C1_0201
R_TYPE_SEL: 2.2; CPF0201D7K68C1_0201
SJ1: ESP32_C6_LIBRARY_7_JUMPER_SJ
SW_DN: 2025-10-22_07-23-44_LIBRARY_EVP-AKE31ASW_EVP-AKE3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; 2025-10-22_07-23-44_LIBRARY_SW_EVP-AKE31A_PAN
SW_ENT: 2025-10-22_07-23-44_LIBRARY_EVP-AKE31ASW_EVP-AKE3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; 2025-10-22_07-23-44_LIBRARY_SW_EVP-AKE31A_PAN
SW_UP: 2025-10-22_07-23-44_LIBRARY_EVP-AKE31ASW_EVP-AKE3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; 2025-10-22_07-23-44_LIBRARY_SW_EVP-AKE31A_PAN
TP_3.3V, TP_3V3: HECTOR_WATCH_1_TPTP20R; HECTOR_WATCH_1_TP20R
TP_BAT_GND: HECTOR_WATCH_1_TPTP20R; HECTOR_WATCH_1_TP20R
TP_GND: HECTOR_WATCH_1_TPTP20R; HECTOR_WATCH_1_TP20R
TP_ON: HECTOR_WATCH_1_TPTP20R; HECTOR_WATCH_1_TP20R
TP_OP: HECTOR_WATCH_1_TPTP20R; HECTOR_WATCH_1_TP20R
TP_RESET: HECTOR_WATCH_1_TPTP20R; HECTOR_WATCH_1_TP20R
TP_SCL: HECTOR_WATCH_1_TPTP20R; HECTOR_WATCH_1_TP20R
TP_SDA: HECTOR_WATCH_1_TPTP20R; HECTOR_WATCH_1_TP20R
TP_SWDCLK: HECTOR_WATCH_1_TPTP20R; HECTOR_WATCH_1_TP20R
TP_SWDIO: HECTOR_WATCH_1_TPTP20R; HECTOR_WATCH_1_TP20R
TP_SWO: HECTOR_WATCH_1_TPTP20R; HECTOR_WATCH_1_TP20R
TP_VBAT: HECTOR_WATCH_1_TPTP20R; HECTOR_WATCH_1_TP20R
TP_VREG: HECTOR_WATCH_1_TPTP20R; HECTOR_WATCH_1_TP20R
U1: NRF52840_QF; NORDIC_NRF_4_AQFN50P700X700X85_HS-74N
U3: MAX17048G+T10; ESP32_C6_LIBRARY_SON50P200X200X80-9N
X1: 32MHz; NORDIC_NRF_BT-XTAL_2016_N
X2: 32.768kHz; NORDIC_NRF_1_XTAL_3215_N

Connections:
3V3/1.7D: C34.2, IC2.C2 (VDD), R5.2, R7.2, R8.2
3V3/2.4A: C6.1, C7.1, C8.1, C12.1, C14.1, C19.1, C25.1, C33.1, IC3.3 (VDDIO), IC3.7 (VDD), IC3.10 (CSB), IC9.E2 (VOUT_1), IC9.E3 (VOUT_2), J2.1, R17.1, R18.1, TP_3.3V.TP, TP_3V3.TP, U1.P$A22 (VDD), U1.P$AD14 (VDD), U1.P$AD23 (VDD), U1.P$B1 (VDD), U1.P$W1 (VDD), U1.P$Y2 (VDDH)
10K: IC1.D1 (TS/MR), R1.2
ALERT/1.6C: U3.5 (!ALERT)
ALERT/2.5C: U1.P$J24 (P0.10/NFC2)
D+/1.5D: D3.4 (I/O2_2)
D+/2.7D: U1.P$AD6 (D+)
D-/1.5D: D3.6 (I/O1_2)
D-/2.7D: U1.P$AD4 (D-)
DN: D3.1 (I/O1_1), J4.A7 (DN1), J4.B7 (DN2)
DP: D3.3 (I/O2_1), J4.A6 (DP1), J4.B6 (DP2)
EPD_3V3: C1-EP-DR.1, EPD-C5.2, J1.15, J1.16, L5.2
EPD_BUSY/1.5D: J1.9
EPD_BUSY/2.2D: U1.P$AD12 (P0.17)
EPD_CS/1.4C: J1.12
EPD_CS/2.2D: U1.P$K2 (P0.05/AIN3)
EPD_DC/1.5D: J1.11
EPD_DC/2.2D: U1.P$AD10 (P0.15)
EPD_RST/1.5D: J1.10
EPD_RST/2.2D: U1.P$AC11 (P0.16)
GDR: J1.2, Q3.1 (G), R2_EP_DR.2
GND: C1.2, C1-EP-DR.2, C2.2, C3.2, C4.2, C5.2, C6.2, C7.2, C8.2, C9.2, C10.2, C11.2, C12.2, C13.2, C14.2, C15.2, C16.2, C17.1, C18.1, C19.2, C20.2, C21.2, C22.2, C23.1, C24.1, C25.2, C27.1, C29.1, C30.1, C31.1, C32.1, C33.2, C34.1, C37.1, C38.1, C39.2, C42.1, C43.2, D3.2 (GND), D4.1 (K), EPD-C5.1, EPD_C1.1, EPD_C2.1, EPD_C6.1, EPD_C7.1, EPD_C8.1, EPD_C9.1, EPD_C10.1, EPD_C11.1, EPD_C12.1, IC1.D2 (GND), IC2.B1 (IN/TRIG), IC2.B3 (GND), IC3.8 (GNDIO), IC3.9 (GND), IC9.B1 (VSEL), IC9.C1 (AGND), IC9.C2 (PGND_1), IC9.C3 (PGND_2), J1.8, J1.17, J1.MP1, J1.MP2, J2.3, J2.5, J4.A1_B12 (GND), J4.A12_B1 (GND), J4.SH1 (SHIELD), J4.SH2 (SHIELD), J4.SH3 (SHIELD), J4.SH4 (SHIELD), R1.1, R1_USB.1, R2_EP_DR.1, R2_USB.2, R3.1, R_TYPE_SEL.1, SJ1.1, SW_DN.1, SW_ENT.1, SW_UP.1, TP_BAT_GND.TP, TP_GND.TP, U1.P$74 (VSS_PAD), U1.P$75 (VSS_PAD), U1.P$76 (VSS_PAD), U1.P$77 (VSS_PAD), U1.P$78 (VSS_PAD), U1.P$79 (VSS_PAD), U1.P$80 (VSS_PAD), U1.P$81 (VSS_PAD), U1.P$82 (VSS_PAD), U1.P$83 (VSS_PAD), U1.P$84 (VSS_PAD), U1.P$85 (VSS_PAD), U1.P$86 (VSS_PAD), U1.P$87 (VSS_PAD), U1.P$88 (VSS_PAD), U1.P$89 (VSS_PAD), U1.P$90 (VSS_PAD), U1.P$B7 (VSS), U1.P$F23 (VSS_PA), U3.1 (CTG), U3.4 (GND), U3.6 (QSTRT), U3.9 (EP), X1.2, X1.4
HAPTIC_EN/1.4C: IC2.A1 (EN)
HAPTIC_EN/2.6A: U1.P$U1 (P0.12)
IMU_INT1: IC3.5 (INT1), U1.P$N1 (P0.08)
IMU_INT2: IC3.6 (INT2), U1.P$P2 (P1.08)
LX1: IC9.B2 (SW1_1), IC9.B3 (SW1_2), L7.1
LX2: IC9.D2 (SW2_1), IC9.D3 (SW2_2), L7.2
MOSI/1.5D: J1.14
MOSI/2.2D: U1.P$B13 (P0.03/AIN1)
unnamed: IC9.D1 (SCL), R4.2
unnamed: IC3.1 (SDO), R3.2
unnamed: C9.1, U1.P$N24 (DEC5)
unnamed: IC9.E1 (SDA), R2.2
unnamed: C20.1, U1.P$AC5 (DEC3V3)
unnamed: C3.1, L1.1, U1.P$H23 (ANT)
unnamed: ANT1.1 (FEED), C4.1, C22.1, L1.2
unnamed: C1.1, U1.P$B24 (XC1), X1.1
unnamed: C2.1, U1.P$A23 (XC2), X1.3
unnamed: C13.1, U1.P$A18 (DEC2)
unnamed: C11.1, U1.P$D23 (DEC3)
unnamed: C10.1, C15.1, C16.1, L3.2, U1.P$B5 (DEC4), U1.P$E24 (DEC6)
unnamed: L2.1, U1.P$B3 (DCC)
unnamed: L2.2, L3.1
unnamed: C5.1, U1.P$C1 (DEC1)
unnamed: C17.2, U1.P$D2 (P0.00/XL1), X2.1
unnamed: C2-EP-DR.2, D5.2 (A), L5.1, Q3.3 (D)
unnamed: C18.2, U1.P$F2 (P0.01/XL2), X2.2
unnamed: C2-EP-DR.1, D2.1 (K), D4.2 (A)
unnamed: R1_EP_DR.1, R_TYPE_SEL.2, SJ1.2
unnamed: Q1.1 (G), R_POWER_EPD.1
unnamed: EPD_C1.2, J1.4
unnamed: EPD_C2.2, J1.5
unnamed: EPD_C6.2, J1.18
unnamed: J4.B5 (CC2), R2_USB.1
unnamed: EPD_C7.2, J1.19
unnamed: C32.2, IC2.A2 (REG)
unnamed: EPD_C8.2, J1.20
unnamed: J4.A5 (CC1), R1_USB.2
unnamed: EPD_C10.2, J1.22
unnamed: EPD_C12.2, J1.24
OUT+: IC2.A3 (OUT+)
OUT-: IC2.C3 (OUT-)
P0.04: U1.P$J1 (P0.04/AIN2)
P0.09: U1.P$L24 (P0.09/NFC1)
P0.13/1.5D: C30.2, R5.1, SW_UP.2
P0.13/2.6C: U1.P$AD8 (P0.13)
P0.14/1.5D: C31.2, R8.1, SW_ENT.2
P0.14/2.7C: U1.P$AC9 (P0.14)
P0.19: U1.P$AC15 (P0.19)
P0.20: U1.P$AD16 (P0.20)
P0.21: U1.P$AC17 (P0.21)
P0.22: U1.P$AD18 (P0.22)
P0.23: U1.P$AC19 (P0.23)
P0.24: U1.P$AD20 (P0.24)
P0.25: U1.P$AC21 (P0.25)
P0.26: U1.P$G1 (P0.26)
P0.27: U1.P$H2 (P0.27)
P0.28: U1.P$B11 (P0.28/AIN4)
P0.29: U1.P$A10 (P0.29/AIN5)
P0.30: U1.P$B9 (P0.30/AIN6)
P0.31: U1.P$A8 (P0.31/AIN7)
P1.01/2.4B: U1.P$Y23 (P1.01)
P1.02/1.6C: C29.2, R7.1, SW_DN.2
P1.02/2.8C: U1.P$W24 (P1.02)
P1.03: U1.P$V23 (P1.03)
P1.04: U1.P$U24 (P1.04)
P1.05: U1.P$T23 (P1.05)
P1.06: U1.P$R24 (P1.06)
P1.07: U1.P$P23 (P1.07)
P1.09: U1.P$R1 (P1.09)
P1.10: U1.P$A20 (P1.10)
P1.11: U1.P$B19 (P1.11)
P1.12: U1.P$B17 (P1.12)
P1.13: U1.P$A16 (P1.13)
P1.14: U1.P$B15 (P1.14)
P1.15: U1.P$A14 (P1.15)
PMIC_INT: IC1.A1 (!INT), U1.P$T2 (P0.11)
PREVGH: D5.1 (K), EPD_C9.2, J1.21
PREVGL: D2.2 (A), EPD_C11.2, J1.23
RESE: J1.3, Q3.2 (S), R1_EP_DR.2
RESET: J2.6, TP_RESET.TP, U1.P$AC13 (P0.18/RESET)
SCK/1.5D: J1.13
SCK/2.2D: U1.P$A12 (P0.02/AIN0)
SCL/1.4C: IC2.C1 (SCL), U3.7 (SCL)
SCL/2.4C: IC1.B1 (SCL), IC3.12 (SCX), R4.1, R17.2, TP_SCL.TP, U1.P$M2 (P0.07)
SDA/1.4C: IC2.B2 (SDA), U3.8 (SDA)
SDA/2C: IC1.C1 (SDA), IC3.2 (SDX), R2.1, R18.2, TP_SDA.TP, U1.P$L1 (P0.06)
SWDCLK: J2.4, TP_SWDCLK.TP, U1.P$AA24 (SWDCLK)
SWDIO: J2.2, TP_SWDIO.TP, U1.P$AC24 (SWDIO)
SWO: TP_SWO.TP, U1.P$AD22 (P1.00)
VBAT/1.2A: C27.2, TP_VBAT.TP, U3.2 (CELL), U3.3 (VDD)
VBAT/2.5C: C37.2, IC1.C2 (BAT)
VBUS/1.5D: C42.2, C43.1, D3.5 (VBUS), J4.A4_B9 (VBUS), J4.A9_B4 (VBUS)
VBUS/2.6D: C21.1, C38.2, IC1.A2 (IN), U1.P$AD2 (VBUS)
VREG: C23.2, C24.2, C39.1, IC1.B2 (SYS), IC9.A1 (EN), IC9.A2 (VIN_1), IC9.A3 (VIN_2), TP_VREG.TP

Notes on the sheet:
LiPo Charger
DC/DC
IMU
N.C.
SWD
DEC3
DEC4_6
DEC1
P0.00/XL1
P0.01/XL2
MCU, Power, IMU, SWD
drawn by: Stan Albert
E-Paper Drive Circuit
DMG2305UX-7
Fuel Gauge
Haptic Driver
Buttons
USB C Connector & ESD Protection
E-Paper Display Connector
E-Paper & Peripherals

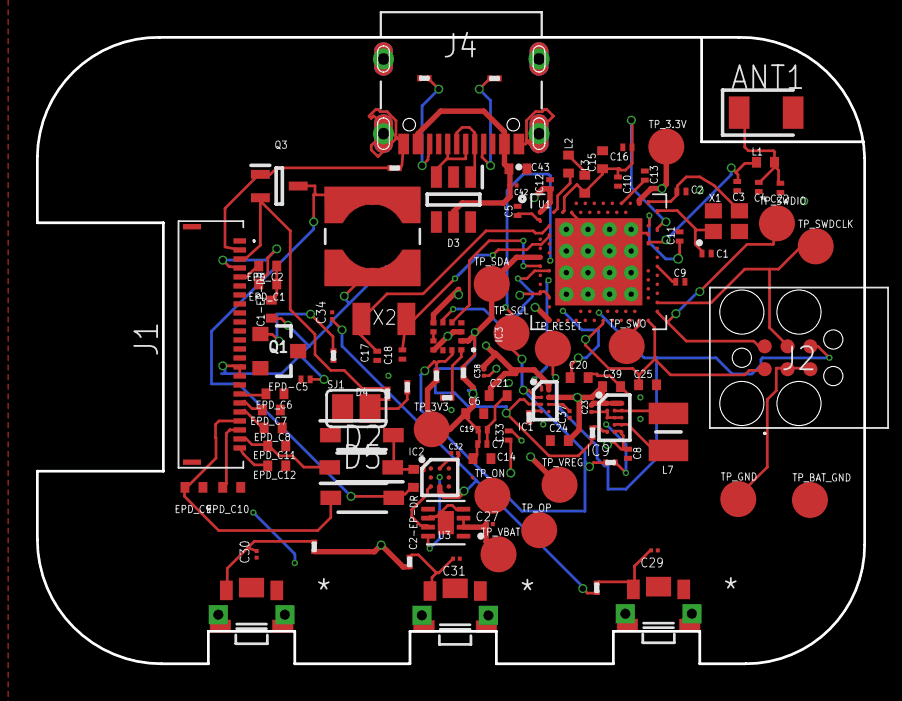
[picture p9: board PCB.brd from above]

Board: 4 copper layers, 46.0 x 34.8 mm, 105 parts (0 on the bottom side), 63 nets.

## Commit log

2026-04-14 Manufacturing stage
    [Bill pf Materials.bom.csv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]
2026-04-19 PCB v2
    [PCB.brd]
2026-04-19 Mechanical Stage
2026-04-19 PCB v3
    [PCB.brd]

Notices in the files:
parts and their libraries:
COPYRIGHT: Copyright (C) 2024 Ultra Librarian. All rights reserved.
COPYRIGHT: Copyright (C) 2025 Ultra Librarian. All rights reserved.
